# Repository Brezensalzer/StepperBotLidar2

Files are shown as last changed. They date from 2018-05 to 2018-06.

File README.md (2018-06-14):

# StepperBotLidar2

Rotating 360 degree Lidar based on the TF Mini sensor. This is a part of a larger robot project. 
The whole rover is "layered" in three slices:

- the chassis layer: https://github.com/Brezensalzer/StepperBotChassis
- the control layer: https://github.com/Brezensalzer/StepperBotController
- the sensor layer: https://github.com/Brezensalzer/StepperBotLidar2
- the ground station code: https://github.com/Brezensalzer/StepperBotGroundStation (with BreezySLAM support!)

Arduino Code is for a Bluepill board but should be easily adaptable to other boards. 
Openscad, FreeCAD drawings and STL files are provided for 3D printing.

To complete the mechanical build, the following parts are needed:
- TF Mini Lidar
- Stepper motor 8HS11-0204S (bought from stepperonline)
- Pololu DRV8834 Low-Voltage Stepper Motor Driver Carrier
- Ball bearing SS6000ZZ 26x10x8 V2A
- ca. 2cm of 10mm aluminium pipe
- Slip ring with 12.5mm, 300rpm, 6 wires
- GT2 timing belt 200mm
- Optional: Pololu Mini Pushbutton Power Switch with Reverse Voltage Protection, LV

The drive pulley on the stepper motor has 30 teeth, the pulley on the turntable has 54 teeth. One full step (1.8°) of the stepper motor is transmitted to a 1° step on the turntable.

Short video clip: https://youtu.be/fx5sSlf0POA

<p align="center">
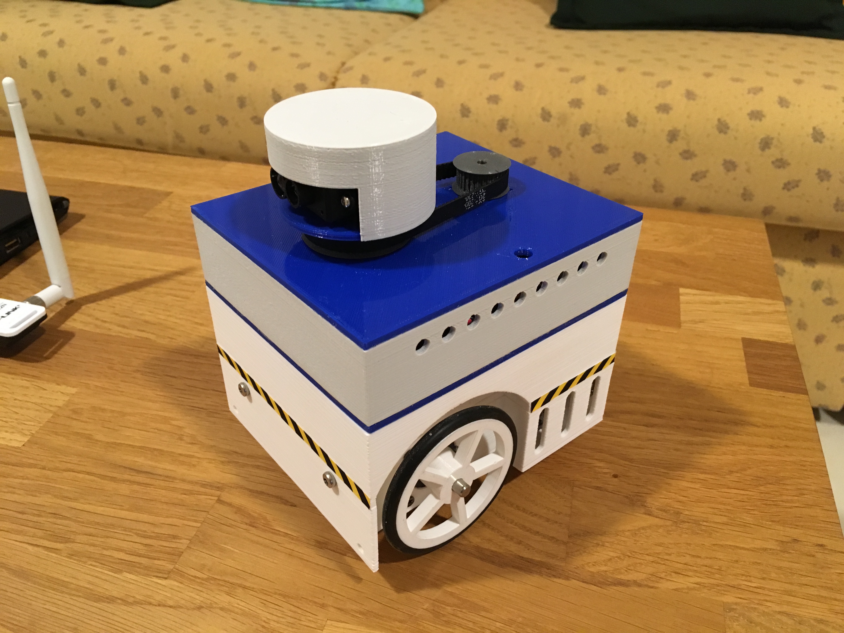
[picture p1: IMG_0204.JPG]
  
</p>

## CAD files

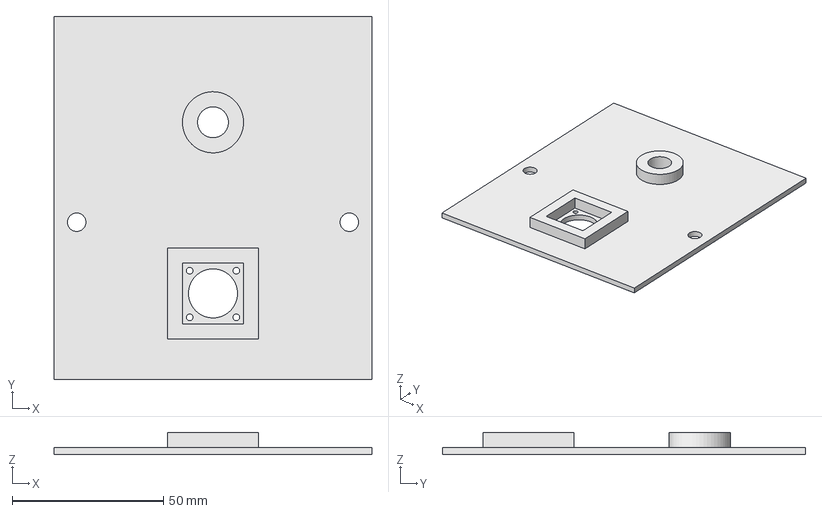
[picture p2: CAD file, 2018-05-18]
3D_parts/LidarBase2.FCStd
105.0 x 120.0 x 7.40 mm

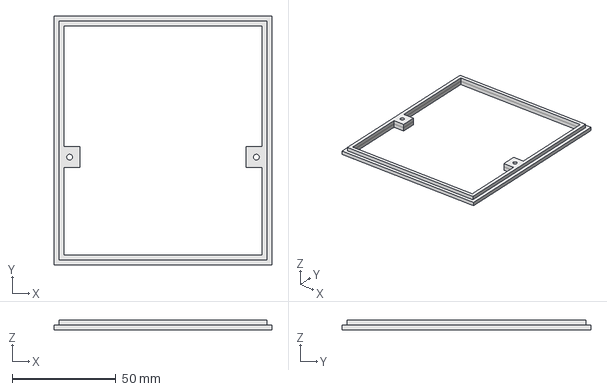
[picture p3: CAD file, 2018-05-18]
3D_parts/LidarChassis1.FCStd
105.0 x 120.0 x 4.80 mm

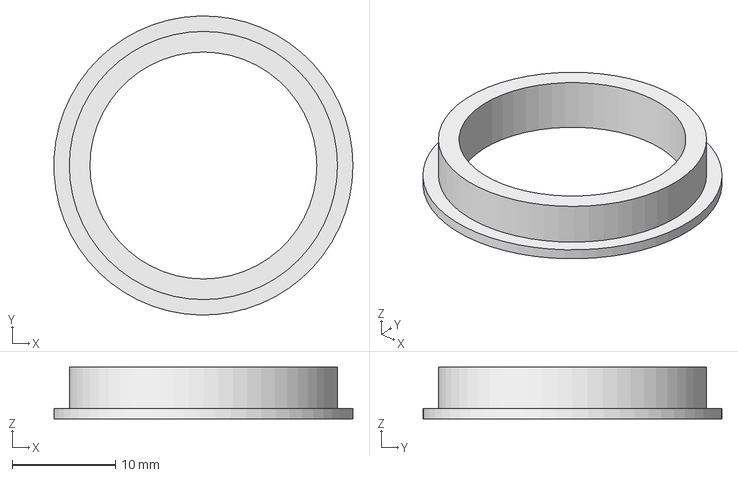
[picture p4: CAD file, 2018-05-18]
3D_parts/Montagering.FCStd
29.0 x 29.0 x 5.00 mm

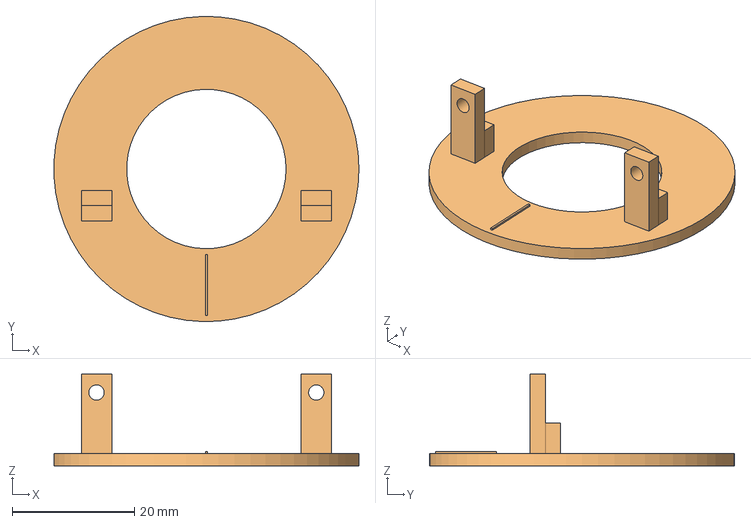
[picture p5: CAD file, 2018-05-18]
3D_parts/Drehteller.FCStd
50.0 x 50.0 x 15.0 mm

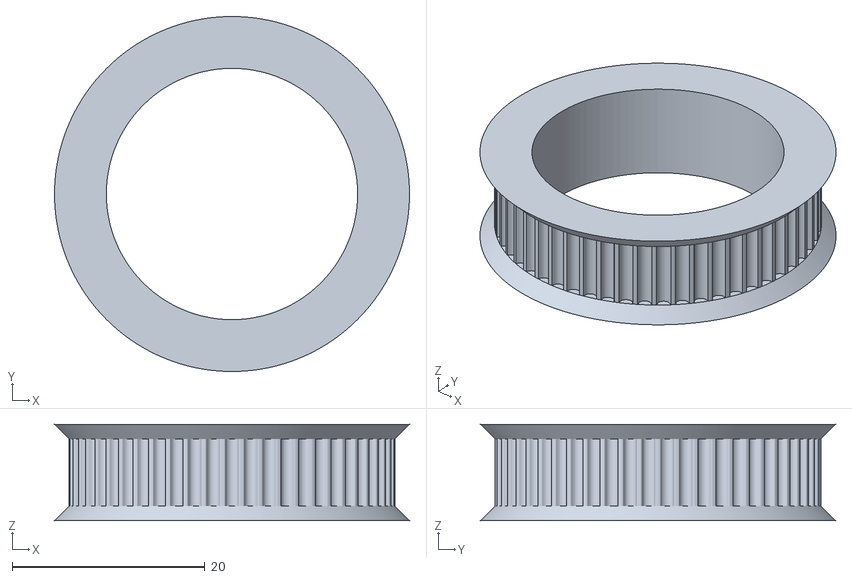
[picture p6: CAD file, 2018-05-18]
3D_parts/Pulley_large.stl
36.9 x 36.9 x 10.0

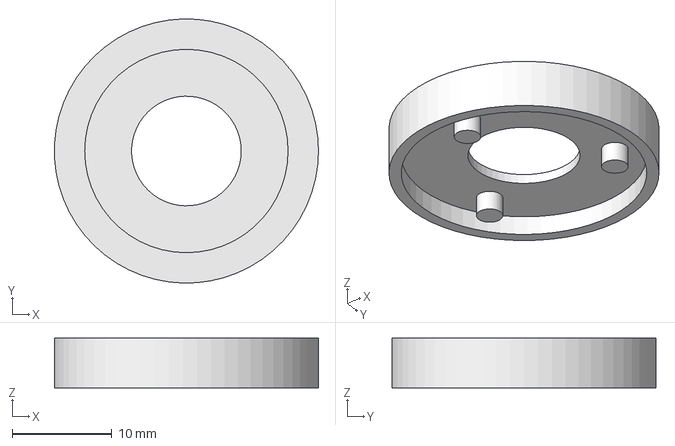
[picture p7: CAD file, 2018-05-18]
3D_parts/Drehdurchfuehrung.FCStd
26.5 x 26.5 x 5.00 mm

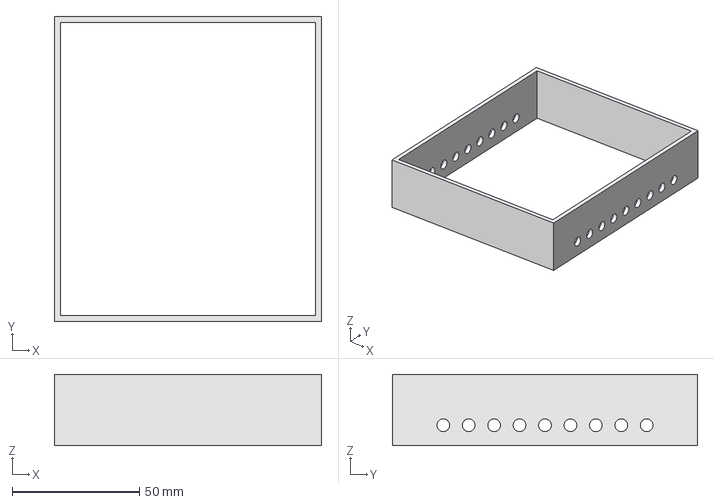
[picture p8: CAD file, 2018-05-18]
3D_parts/LidarChassis2.FCStd
105.0 x 120.0 x 28.0 mm

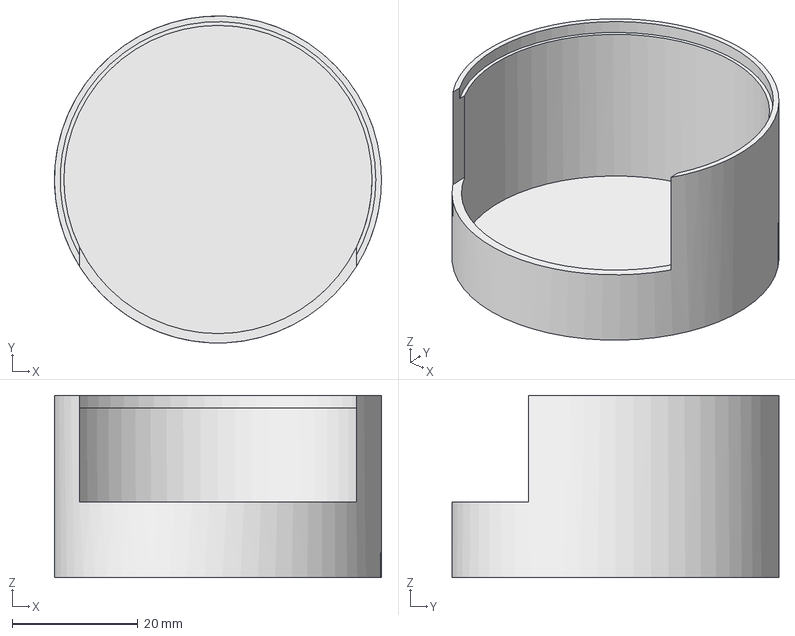
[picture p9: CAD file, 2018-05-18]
3D_parts/Deckel.FCStd
52.0 x 52.0 x 29.0 mm

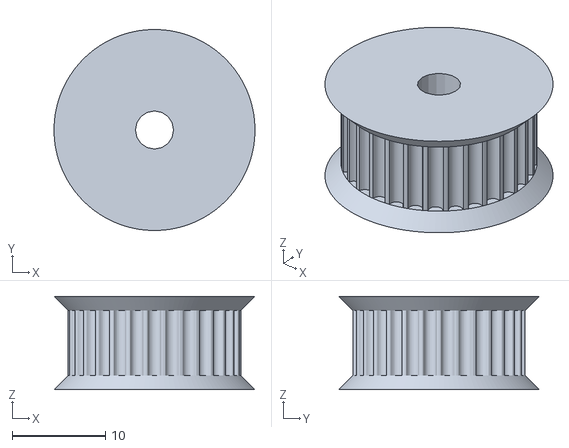
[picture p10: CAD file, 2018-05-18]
3D_parts/Pulley_small.stl
21.6 x 21.6 x 10.0

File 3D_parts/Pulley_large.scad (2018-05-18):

// Parametric Pulley with multiple belt profiles
// by droftarts January 2012

// Based on pulleys by:
// http://www.thingiverse.com/thing:11256 by me!
// https://github.com/prusajr/PrusaMendel by Josef Prusa
// http://www.thingiverse.com/thing:3104 by GilesBathgate
// http://www.thingiverse.com/thing:2079 by nophead

// dxf tooth data from http://oem.cadregister.com/asp/PPOW_Entry.asp?company=915217&elementID=07807803/METRIC/URETH/WV0025/F
// pulley diameter checked and modelled from data at http://www.sdp-si.com/D265/HTML/D265T016.html

/**
 * @name Pulley
 * @category Printed
 * @using 1 x m3 nut, normal or nyloc
 * @using 1 x m3x10 set screw or 1 x m3x8 grub screw
 */


// tuneable constants

teeth = 54;			// Number of teeth, standard Mendel T5 belt = 8, gives Outside Diameter of 11.88mm
profile = 12;		// 1=MXL 2=40DP 3=XL 4=H 5=T2.5 6=T5 7=T10 8=AT5 9=HTD_3mm 10=HTD_5mm 11=HTD_8mm 12=GT2_2mm 13=GT2_3mm 14=GT2_5mm

motor_shaft = 26.1;	// NEMA17 motor shaft exact diameter = 5
m3_dia = 3.2;		// 3mm hole diameter
m3_nut_hex = 1;		// 1 for hex, 0 for square nut
m3_nut_flats = 5.7;	// normal M3 hex nut exact width = 5.5
m3_nut_depth = 2.7;	// normal M3 hex nut exact depth = 2.4, nyloc = 4

retainer = 1;		// Belt retainer above teeth, 0 = No, 1 = Yes
retainer_ht = 1.5;	// height of retainer flange over pulley, standard = 1.5
idler = 1;			// Belt retainer below teeth, 0 = No, 1 = Yes
idler_ht = 1.5;		// height of idler flange over pulley, standard = 1.5

pulley_t_ht = 7;	// length of toothed part of pulley, standard = 12
pulley_b_ht = 6;		// pulley base height, standard = 8. Set to same as idler_ht if you want an idler but no pulley.
pulley_b_dia = 20;	// pulley base diameter, standard = 20
no_of_nuts = 0;		// number of captive nuts required, standard = 1
nut_angle = 90;		// angle between nuts, standard = 90
nut_shaft_distance = 1.2;	// distance between inner face of nut and shaft, can be negative.


//	********************************
//	** Scaling tooth for good fit **
//	********************************
/*	To improve fit of belt to pulley, set the following constant. Decrease or increase by 0.1mm at a time. We are modelling the *BELT* tooth here, not the tooth on the pulley. Increasing the number will *decrease* the pulley tooth size. Increasing the tooth width will also scale proportionately the tooth depth, to maintain the shape of the tooth, and increase how far into the pulley the tooth is indented. Can be negative */

additional_tooth_width = 0.2; //mm

//	If you need more tooth depth than this provides, adjust the following constant. However, this will cause the shape of the tooth to change.

additional_tooth_depth = 0; //mm

// calculated constants

nut_elevation = pulley_b_ht/2;
m3_nut_points = 2*((m3_nut_flats/2)/cos(30)); // This is needed for the nut trap

// The following set the pulley diameter for a given number of teeth

MXL_pulley_dia = tooth_spacing (2.032,0.254);
40DP_pulley_dia = tooth_spacing (2.07264,0.1778);
XL_pulley_dia = tooth_spacing (5.08,0.254);
H_pulley_dia = tooth_spacing (9.525,0.381);
T2_5_pulley_dia = tooth_spaceing_curvefit (0.7467,0.796,1.026);
T5_pulley_dia = tooth_spaceing_curvefit (0.6523,1.591,1.064);
T10_pulley_dia = tooth_spacing (10,0.93);
AT5_pulley_dia = tooth_spaceing_curvefit (0.6523,1.591,1.064);
HTD_3mm_pulley_dia = tooth_spacing (3,0.381);
HTD_5mm_pulley_dia = tooth_spacing (5,0.5715);
HTD_8mm_pulley_dia = tooth_spacing (8,0.6858);
GT2_2mm_pulley_dia = tooth_spacing (2,0.254);
GT2_3mm_pulley_dia = tooth_spacing (3,0.381);
GT2_5mm_pulley_dia = tooth_spacing (5,0.5715);

// The following calls the pulley creation part, and passes the pulley diameter and tooth width to that module

if ( profile == 1 ) { pulley ( "MXL" , MXL_pulley_dia , 0.508 , 1.321 ); }
if ( profile == 2 ) { pulley ( "40 D.P." , 40DP_pulley_dia , 0.457 , 1.226 ); }
if ( profile == 3 ) { pulley ( "XL" , XL_pulley_dia , 1.27, 3.051 ); }
if ( profile == 4 ) { pulley ( "H" , H_pulley_dia ,1.905 , 5.359 ); }
if ( profile == 5 ) { pulley ( "T2.5" , T2_5_pulley_dia , 0.7 , 1.678 ); }
if ( profile == 6 ) { pulley ( "T5" , T5_pulley_dia , 1.19 , 3.264 ); }
if ( profile == 7 ) { pulley ( "T10" , T10_pulley_dia , 2.5 , 6.13 ); }
if ( profile == 8 ) { pulley ( "AT5" , AT5_pulley_dia , 1.19 , 4.268 ); }
if ( profile == 9 ) { pulley ( "HTD 3mm" , HTD_3mm_pulley_dia , 1.289 , 2.27 ); }
if ( profile == 10 ) { pulley ( "HTD 5mm" , HTD_5mm_pulley_dia , 2.199 , 3.781 ); }
if ( profile == 11 ) { pulley ( "HTD 8mm" , HTD_8mm_pulley_dia , 3.607 , 6.603 ); }
if ( profile == 12 ) { pulley ( "GT2 2mm" , GT2_2mm_pulley_dia , 0.764 , 1.494 ); }
if ( profile == 13 ) { pulley ( "GT2 3mm" , GT2_3mm_pulley_dia , 1.169 , 2.31 ); }
if ( profile == 14 ) { pulley ( "GT2 5mm" , GT2_5mm_pulley_dia , 1.969 , 3.952 ); }

// Functions

function tooth_spaceing_curvefit (b,c,d)
	= ((c * pow(teeth,d)) / (b + pow(teeth,d))) * teeth ;

function tooth_spacing(tooth_pitch,pitch_line_offset)
	= (2*((teeth*tooth_pitch)/(3.14159265*2)-pitch_line_offset)) ;

// Main Module

module pulley( belt_type , pulley_OD , tooth_depth , tooth_width )
	{
	echo (str("Belt type = ",belt_type,"; Number of teeth = ",teeth,"; Pulley Outside Diameter = ",pulley_OD,"mm "));
	tooth_distance_from_centre = sqrt( pow(pulley_OD/2,2) - pow((tooth_width+additional_tooth_width)/2,2));
	tooth_width_scale = (tooth_width + additional_tooth_width ) / tooth_width;
	tooth_depth_scale = ((tooth_depth + additional_tooth_depth ) / tooth_depth) ;


//	************************************************************************
//	*** uncomment the following line if pulley is wider than puller base ***
//	************************************************************************

//	translate ([0,0, pulley_b_ht + pulley_t_ht + retainer_ht ]) rotate ([0,180,0])

	difference()
	 {	 
		union()
		{
			//base
	
			if ( pulley_b_ht < 2 ) { echo ("CAN'T DRAW PULLEY BASE, HEIGHT LESS THAN 2!!!"); } else {
				rotate_extrude($fn=pulley_b_dia*2)
				{
						square([pulley_b_dia/2-1,pulley_b_ht]);
						square([pulley_b_dia/2,pulley_b_ht-1]);
						translate([pulley_b_dia/2-1,pulley_b_ht-1]) circle(1);
				}
			}
	
		difference()
			{
			//shaft - diameter is outside diameter of pulley
			
			translate([0,0,pulley_b_ht]) 
			rotate ([0,0,360/(teeth*4)]) 
			cylinder(r=pulley_OD/2,h=pulley_t_ht, $fn=teeth*4);
	
			//teeth - cut out of shaft
		
			for(i=[1:teeth]) 
			rotate([0,0,i*(360/teeth)])
			translate([0,-tooth_distance_from_centre,pulley_b_ht -1]) 
			scale ([ tooth_width_scale , tooth_depth_scale , 1 ]) 
			{
			if ( profile == 1 ) { MXL();}
			if ( profile == 2 ) { 40DP();}
			if ( profile == 3 ) { XL();}
			if ( profile == 4 ) { H();}
			if ( profile == 5 ) { T2_5();}
			if ( profile == 6 ) { T5();}
			if ( profile == 7 ) { T10();}
			if ( profile == 8 ) { AT5();}
			if ( profile == 9 ) { HTD_3mm();}
			if ( profile == 10 ) { HTD_5mm();}
			if ( profile == 11 ) { HTD_8mm();}
			if ( profile == 12 ) { GT2_2mm();}
			if ( profile == 13 ) { GT2_3mm();}
			if ( profile == 14 ) { GT2_5mm();}
			}

			}
			
		//belt retainer / idler
		if ( retainer > 0 ) {translate ([0,0, pulley_b_ht + pulley_t_ht ]) 
		rotate_extrude($fn=teeth*4)  
		polygon([[0,0],[pulley_OD/2,0],[pulley_OD/2 + retainer_ht , retainer_ht],[0 , retainer_ht],[0,0]]);}
		
		if ( idler > 0 ) {translate ([0,0, pulley_b_ht - idler_ht ]) 
		rotate_extrude($fn=teeth*4)  
		polygon([[0,0],[pulley_OD/2 + idler_ht,0],[pulley_OD/2 , idler_ht],[0 , idler_ht],[0,0]]);}
	
		}
	   
		//hole for motor shaft
		translate([0,0,-1])cylinder(r=motor_shaft/2,h=pulley_b_ht + pulley_t_ht + retainer_ht + 2,$fn=motor_shaft*4);
				
		//captive nut and grub screw holes
	
		if ( pulley_b_ht < m3_nut_flats ) { echo ("CAN'T DRAW CAPTIVE NUTS, HEIGHT LESS THAN NUT DIAMETER!!!"); } else {
		if ( (pulley_b_dia - motor_shaft)/2 < m3_nut_depth + 3 ) { echo ("CAN'T DRAW CAPTIVE NUTS, DIAMETER TOO SMALL FOR NUT DEPTH!!!"); } else {
	
			for(j=[1:no_of_nuts]) rotate([0,0,j*nut_angle])
			translate([0,0,nut_elevation])rotate([90,0,0])
	
			union()
			{
				//entrance
				translate([0,-pulley_b_ht/4-0.5,motor_shaft/2+m3_nut_depth/2+nut_shaft_distance]) cube([m3_nut_flats,pulley_b_ht/2+1,m3_nut_depth],center=true);
	
				//nut
				if ( m3_nut_hex > 0 )
					{
						// hex nut
						translate([0,0.25,motor_shaft/2+m3_nut_depth/2+nut_shaft_distance]) rotate([0,0,30]) cylinder(r=m3_nut_points/2,h=m3_nut_depth,center=true,$fn=6);
					} else {
						// square nut
						translate([0,0.25,motor_shaft/2+m3_nut_depth/2+nut_shaft_distance]) cube([m3_nut_flats,m3_nut_flats,m3_nut_depth],center=true);
					}
	
				//grub screw hole
				rotate([0,0,22.5])cylinder(r=m3_dia/2,h=pulley_b_dia/2+1,$fn=8);
			}
		}}
	 }
	   
	}


// Tooth profile modules
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

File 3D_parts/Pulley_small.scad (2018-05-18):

// Parametric Pulley with multiple belt profiles
// by droftarts January 2012

// Based on pulleys by:
// http://www.thingiverse.com/thing:11256 by me!
// https://github.com/prusajr/PrusaMendel by Josef Prusa
// http://www.thingiverse.com/thing:3104 by GilesBathgate
// http://www.thingiverse.com/thing:2079 by nophead

// dxf tooth data from http://oem.cadregister.com/asp/PPOW_Entry.asp?company=915217&elementID=07807803/METRIC/URETH/WV0025/F
// pulley diameter checked and modelled from data at http://www.sdp-si.com/D265/HTML/D265T016.html

/**
 * @name Pulley
 * @category Printed
 * @using 1 x m3 nut, normal or nyloc
 * @using 1 x m3x10 set screw or 1 x m3x8 grub screw
 */


// tuneable constants

teeth = 30;			// Number of teeth, standard Mendel T5 belt = 8, gives Outside Diameter of 11.88mm
profile = 12;		// 1=MXL 2=40DP 3=XL 4=H 5=T2.5 6=T5 7=T10 8=AT5 9=HTD_3mm 10=HTD_5mm 11=HTD_8mm 12=GT2_2mm 13=GT2_3mm 14=GT2_5mm

motor_shaft = 4.1;	// NEMA17 motor shaft exact diameter = 5
m3_dia = 3.2;		// 3mm hole diameter
m3_nut_hex = 1;		// 1 for hex, 0 for square nut
m3_nut_flats = 5.7;	// normal M3 hex nut exact width = 5.5
m3_nut_depth = 2.7;	// normal M3 hex nut exact depth = 2.4, nyloc = 4

retainer = 1;		// Belt retainer above teeth, 0 = No, 1 = Yes
retainer_ht = 1.5;	// height of retainer flange over pulley, standard = 1.5
idler = 1;			// Belt retainer below teeth, 0 = No, 1 = Yes
idler_ht = 1.5;		// height of idler flange over pulley, standard = 1.5

pulley_t_ht = 7;	// length of toothed part of pulley, standard = 12
pulley_b_ht = 1.5;		// pulley base height, standard = 8. Set to same as idler_ht if you want an idler but no pulley.
pulley_b_dia = 20;	// pulley base diameter, standard = 20
no_of_nuts = 0;		// number of captive nuts required, standard = 1
nut_angle = 90;		// angle between nuts, standard = 90
nut_shaft_distance = 1.2;	// distance between inner face of nut and shaft, can be negative.


//	********************************
//	** Scaling tooth for good fit **
//	********************************
/*	To improve fit of belt to pulley, set the following constant. Decrease or increase by 0.1mm at a time. We are modelling the *BELT* tooth here, not the tooth on the pulley. Increasing the number will *decrease* the pulley tooth size. Increasing the tooth width will also scale proportionately the tooth depth, to maintain the shape of the tooth, and increase how far into the pulley the tooth is indented. Can be negative */

additional_tooth_width = 0.2; //mm

//	If you need more tooth depth than this provides, adjust the following constant. However, this will cause the shape of the tooth to change.

additional_tooth_depth = 0; //mm

// calculated constants

nut_elevation = pulley_b_ht/2;
m3_nut_points = 2*((m3_nut_flats/2)/cos(30)); // This is needed for the nut trap

// The following set the pulley diameter for a given number of teeth

MXL_pulley_dia = tooth_spacing (2.032,0.254);
40DP_pulley_dia = tooth_spacing (2.07264,0.1778);
XL_pulley_dia = tooth_spacing (5.08,0.254);
H_pulley_dia = tooth_spacing (9.525,0.381);
T2_5_pulley_dia = tooth_spaceing_curvefit (0.7467,0.796,1.026);
T5_pulley_dia = tooth_spaceing_curvefit (0.6523,1.591,1.064);
T10_pulley_dia = tooth_spacing (10,0.93);
AT5_pulley_dia = tooth_spaceing_curvefit (0.6523,1.591,1.064);
HTD_3mm_pulley_dia = tooth_spacing (3,0.381);
HTD_5mm_pulley_dia = tooth_spacing (5,0.5715);
HTD_8mm_pulley_dia = tooth_spacing (8,0.6858);
GT2_2mm_pulley_dia = tooth_spacing (2,0.254);
GT2_3mm_pulley_dia = tooth_spacing (3,0.381);
GT2_5mm_pulley_dia = tooth_spacing (5,0.5715);

// The following calls the pulley creation part, and passes the pulley diameter and tooth width to that module

if ( profile == 1 ) { pulley ( "MXL" , MXL_pulley_dia , 0.508 , 1.321 ); }
if ( profile == 2 ) { pulley ( "40 D.P." , 40DP_pulley_dia , 0.457 , 1.226 ); }
if ( profile == 3 ) { pulley ( "XL" , XL_pulley_dia , 1.27, 3.051 ); }
if ( profile == 4 ) { pulley ( "H" , H_pulley_dia ,1.905 , 5.359 ); }
if ( profile == 5 ) { pulley ( "T2.5" , T2_5_pulley_dia , 0.7 , 1.678 ); }
if ( profile == 6 ) { pulley ( "T5" , T5_pulley_dia , 1.19 , 3.264 ); }
if ( profile == 7 ) { pulley ( "T10" , T10_pulley_dia , 2.5 , 6.13 ); }
if ( profile == 8 ) { pulley ( "AT5" , AT5_pulley_dia , 1.19 , 4.268 ); }
if ( profile == 9 ) { pulley ( "HTD 3mm" , HTD_3mm_pulley_dia , 1.289 , 2.27 ); }
if ( profile == 10 ) { pulley ( "HTD 5mm" , HTD_5mm_pulley_dia , 2.199 , 3.781 ); }
if ( profile == 11 ) { pulley ( "HTD 8mm" , HTD_8mm_pulley_dia , 3.607 , 6.603 ); }
if ( profile == 12 ) { pulley ( "GT2 2mm" , GT2_2mm_pulley_dia , 0.764 , 1.494 ); }
if ( profile == 13 ) { pulley ( "GT2 3mm" , GT2_3mm_pulley_dia , 1.169 , 2.31 ); }
if ( profile == 14 ) { pulley ( "GT2 5mm" , GT2_5mm_pulley_dia , 1.969 , 3.952 ); }

// Functions

function tooth_spaceing_curvefit (b,c,d)
	= ((c * pow(teeth,d)) / (b + pow(teeth,d))) * teeth ;

function tooth_spacing(tooth_pitch,pitch_line_offset)
	= (2*((teeth*tooth_pitch)/(3.14159265*2)-pitch_line_offset)) ;

// Main Module

module pulley( belt_type , pulley_OD , tooth_depth , tooth_width )
	{
	echo (str("Belt type = ",belt_type,"; Number of teeth = ",teeth,"; Pulley Outside Diameter = ",pulley_OD,"mm "));
	tooth_distance_from_centre = sqrt( pow(pulley_OD/2,2) - pow((tooth_width+additional_tooth_width)/2,2));
	tooth_width_scale = (tooth_width + additional_tooth_width ) / tooth_width;
	tooth_depth_scale = ((tooth_depth + additional_tooth_depth ) / tooth_depth) ;


//	************************************************************************
//	*** uncomment the following line if pulley is wider than puller base ***
//	************************************************************************

//	translate ([0,0, pulley_b_ht + pulley_t_ht + retainer_ht ]) rotate ([0,180,0])

	difference()
	 {	 
		union()
		{
			//base
	
			if ( pulley_b_ht < 2 ) { echo ("CAN'T DRAW PULLEY BASE, HEIGHT LESS THAN 2!!!"); } else {
				rotate_extrude($fn=pulley_b_dia*2)
				{
						square([pulley_b_dia/2-1,pulley_b_ht]);
						square([pulley_b_dia/2,pulley_b_ht-1]);
						translate([pulley_b_dia/2-1,pulley_b_ht-1]) circle(1);
				}
			}
	
		difference()
			{
			//shaft - diameter is outside diameter of pulley
			
			translate([0,0,pulley_b_ht]) 
			rotate ([0,0,360/(teeth*4)]) 
			cylinder(r=pulley_OD/2,h=pulley_t_ht, $fn=teeth*4);
	
			//teeth - cut out of shaft
		
			for(i=[1:teeth]) 
			rotate([0,0,i*(360/teeth)])
			translate([0,-tooth_distance_from_centre,pulley_b_ht -1]) 
			scale ([ tooth_width_scale , tooth_depth_scale , 1 ]) 
			{
			if ( profile == 1 ) { MXL();}
			if ( profile == 2 ) { 40DP();}
			if ( profile == 3 ) { XL();}
			if ( profile == 4 ) { H();}
			if ( profile == 5 ) { T2_5();}
			if ( profile == 6 ) { T5();}
			if ( profile == 7 ) { T10();}
			if ( profile == 8 ) { AT5();}
			if ( profile == 9 ) { HTD_3mm();}
			if ( profile == 10 ) { HTD_5mm();}
			if ( profile == 11 ) { HTD_8mm();}
			if ( profile == 12 ) { GT2_2mm();}
			if ( profile == 13 ) { GT2_3mm();}
			if ( profile == 14 ) { GT2_5mm();}
			}

			}
			
		//belt retainer / idler
		if ( retainer > 0 ) {translate ([0,0, pulley_b_ht + pulley_t_ht ]) 
		rotate_extrude($fn=teeth*4)  
		polygon([[0,0],[pulley_OD/2,0],[pulley_OD/2 + retainer_ht , retainer_ht],[0 , retainer_ht],[0,0]]);}
		
		if ( idler > 0 ) {translate ([0,0, pulley_b_ht - idler_ht ]) 
		rotate_extrude($fn=teeth*4)  
		polygon([[0,0],[pulley_OD/2 + idler_ht,0],[pulley_OD/2 , idler_ht],[0 , idler_ht],[0,0]]);}
	
		}
	   
		//hole for motor shaft
		translate([0,0,-1])cylinder(r=motor_shaft/2,h=pulley_b_ht + pulley_t_ht + retainer_ht + 2,$fn=motor_shaft*4);
				
		//captive nut and grub screw holes
	
		if ( pulley_b_ht < m3_nut_flats ) { echo ("CAN'T DRAW CAPTIVE NUTS, HEIGHT LESS THAN NUT DIAMETER!!!"); } else {
		if ( (pulley_b_dia - motor_shaft)/2 < m3_nut_depth + 3 ) { echo ("CAN'T DRAW CAPTIVE NUTS, DIAMETER TOO SMALL FOR NUT DEPTH!!!"); } else {
	
			for(j=[1:no_of_nuts]) rotate([0,0,j*nut_angle])
			translate([0,0,nut_elevation])rotate([90,0,0])
	
			union()
			{
				//entrance
				translate([0,-pulley_b_ht/4-0.5,motor_shaft/2+m3_nut_depth/2+nut_shaft_distance]) cube([m3_nut_flats,pulley_b_ht/2+1,m3_nut_depth],center=true);
	
				//nut
				if ( m3_nut_hex > 0 )
					{
						// hex nut
						translate([0,0.25,motor_shaft/2+m3_nut_depth/2+nut_shaft_distance]) rotate([0,0,30]) cylinder(r=m3_nut_points/2,h=m3_nut_depth,center=true,$fn=6);
					} else {
						// square nut
						translate([0,0.25,motor_shaft/2+m3_nut_depth/2+nut_shaft_distance]) cube([m3_nut_flats,m3_nut_flats,m3_nut_depth],center=true);
					}
	
				//grub screw hole
				rotate([0,0,22.5])cylinder(r=m3_dia/2,h=pulley_b_dia/2+1,$fn=8);
			}
		}}
	 }
	   
	}


// Tooth profile modules
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

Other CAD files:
3D_parts/Deckel.stl
3D_parts/Drehdurchfuehrung.stl
3D_parts/Drehteller.stl
3D_parts/LidarBase2.stl
3D_parts/LidarChassis1.stl
3D_parts/LidarChassis2.stl
3D_parts/Montagering.stl

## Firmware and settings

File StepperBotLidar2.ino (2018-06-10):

/* --------------------------------------------------------------------
 *  StepperBotLidar2
 * --------------------------------------------------------------------
 * Bluepill board STM32F103C8T6
 * 
 * RX1 Pin PA10 (31), 5V tolerant -> TX TF Mini
 * TX1 Pin PA9 (30), 5V tolerant -> RX TF Mini
 * RX3 Pin B11 (22) -> TX5 Beaglebone
 * TX3 Pin B10 (21) -> RX5 Beaglebone
 * Stepper DIR -> PA1
 * Stepper STEP -> PA2
 * Stepper SLEEP -> PA3 Permanently HIGH! Stepper motor needs holding force against slip ring!
 *
 * Stepper motor 200 steps/rev
 * belt drive 30 teeth to 54 teeth
 * => 360 motor steps = turntable 1 revolution
 * LIDAR has to turn counter-clockwise
 */

//--------------------------------------------------------------------------------
// ToF Sensor
//--------------------------------------------------------------------------------
#include "TFMini.h"
#define pinOn  PA4
#define pinOff PA5
TFMini tfmini;
uint16_t distance;
uint16_t strength;
int angle;

//--------------------------------------------------------------------------------
// Stepper
//--------------------------------------------------------------------------------
#include <Arduino.h>
#include "BasicStepperDriver.h"

// Motor steps per revolution. Most steppers are 200 steps or 1.8 degrees/step
#define MOTOR_STEPS 200

// All the wires needed for full functionality
#define DIR PA1
#define STEP PA2
#define ENABLE PA3  // sleep is a keyword ;o)

// Since microstepping is set externally, make sure this matches the selected mode
// 1=full step, 2=half step etc.
#define MICROSTEPS 1

// 2-wire basic config, microstepping is hardwired on the driver
BasicStepperDriver stepper(MOTOR_STEPS, DIR, STEP);

//--------------------------------------------------------------------------------
// command interface
//--------------------------------------------------------------------------------
const char del = '#';   // delimiter
String cmd  = "stop";	// dummy command
String scan = "scan"; 	// start 360 degree scan
String info = "info"; 	// show version info
String ID   = "StepperBotLidar2.ino V2.0";
// auto switch between USB Serial und Serial
boolean USB = true;
int countdown = 2000;

//--------------------------------------------------------------------------------
void setup() {

  // Set target motor RPM
  stepper.setRPM(60);

  // stepper sleep pin
  pinMode(ENABLE, OUTPUT);
  digitalWrite(ENABLE,HIGH);

  // Bluepill check serial connection
  Serial.begin(115200);
  while (!Serial)
    { 
      delay(5);
      countdown--;
      if (countdown == 0)
        {
          USB = false;
          break; 
        }
    }
  if (!USB)
    {
      Serial3.begin(57600);
      while (!Serial3)
        { delay(1); }
    }

  // TF Mini: Initialize the data rate for the Serial port
  Serial1.begin(TFMINI_BAUDRATE);
  pinMode(pinOn, OUTPUT);
  pinMode(pinOff, OUTPUT);

  // Initialize the TF Mini sensor
  tfmini.begin(&Serial1);
  delay(1000);    
}

//--------------------------------------------------------------------------------
void loop() {

  //----------------------------------------------------------------
  // scanning
  //----------------------------------------------------------------
  if (cmd.equals(scan))
  {
    // power on LIDAR
    powerLidar(true);
    delay(100);
    tfmini.setSingleScanMode();

    // workaround for first measurement running wild
    // result is ignored
    tfmini.externalTrigger();
    distance = tfmini.getDistance();
    strength = tfmini.getRecentSignalStrength();
    
    for (angle = 0; angle < 360; angle = angle + 1)
    {
      // Take single measurement 
      tfmini.externalTrigger();
      distance = tfmini.getDistance();
      strength = tfmini.getRecentSignalStrength();
      
      // Display the measurement
      if (USB)
      {
        Serial.print(angle);
        Serial.print(",");
        Serial.print(distance);
        Serial.print(",");
        Serial.println(strength);
      }
      else
      {
        Serial3.print(angle);
        Serial3.print(",");
        Serial3.print(distance);      
        Serial3.print(",");
        Serial3.println(strength);      
      }
      // move turntable 1 degree counter-clockwise
      stepper.move(1*MICROSTEPS);
    }
    cmd = "stop";
    // power off LIDAR
    powerLidar(false);
  }

  //----------------------------------------------------------------
  // version info 
  //----------------------------------------------------------------
  else if (cmd.equals(info))
  {
     if (USB)
     {
       Serial.println(ID);
       Serial.println("Interface: Serial(USB)");
     }
     else
     {
       Serial3.println(ID);
       Serial3.println("Interface: Serial3");
     }
     cmd = "stop"; 
  }
  
  //----------------------------------------------------------------
  // wait for command 
  //----------------------------------------------------------------
  else
  { 
    delay(10);
    if (USB)
      { cmd = Serial.readStringUntil(del); }
    else
      { cmd = Serial3.readStringUntil(del); }
    cmd = cmd.substring(0,4);
  }
}

//--------------------------------------------------------------------------------
void powerLidar(boolean trigger) {
  if (trigger) {
    digitalWrite(pinOn, HIGH);
    delay(10);
    digitalWrite(pinOn, LOW);
  }
  else {
    digitalWrite(pinOff, HIGH);
    delay(10);
    digitalWrite(pinOff, LOW);    
  }  
}

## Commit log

2018-05-18 imported 3D parts
    [Deckel.FCStd, Deckel.stl, Drehdurchfuehrung.FCStd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]
2018-05-18 imported Arduino sketch
2018-05-28 added link to chassis
2018-06-10 added workaround for first measurement running wild
    [StepperBotLidar2.ino]
2018-06-14 updated README with link to ground station code
